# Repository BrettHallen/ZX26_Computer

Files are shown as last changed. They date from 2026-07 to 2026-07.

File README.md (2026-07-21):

# ZX26 Computer
I thought it might be interested to have a crack at designing a simple ZX81 clone that utilised the services of the vLA81.<br>

## [Issue 1](/Issue1)
This is my first attempt, just to see if it'll work.  I have left off the expansion connector for now.<br>

The design includes:
- Gateron low-profile keyswitches
- Dedicated cursor key cluster
- Atari-compatible joystick interface
- "FIRE" selectable between ZERO and SPACE keys
- 32KB of RAM (three schemes selectable via vLA81)
- 32KB of ROM (four switchable 8KB banks, i.e. original BASIC, modernised BASIC, ASZMIC assembler, ZX81 FORTH)
- 5V power in using a USB Type B connector (nice 'n' solid)
- Baseband video output selectable between NTSC (USA) and PAL (UK)

## vLA81
Utilising [VRetro's modern ULA replacement](https://www.vretrodesign.com/products/vla81-zx81-ula-replacement) to simplify parts & design.<br>

## Parts
Refer to the BOM for all parts.<br>

Some specific parts (i.e. footprints) I've utilised are:
- USB Type B: Same Sky UJ2-B-HR-G-TH
- RCA Jack: Kobiconn 156-0099-E
- 3.5mm Mono Jack: Same Sky SJ3-350820B
- DE9 Plug: Amphenol L717SDE09PA4CH4FC309 (or similar)

## Useful Information
- https://oldcomputer.info/8bit/zx81/ULA/ula.htm
- https://hackaday.io/project/192473-zx80zx81-remakes

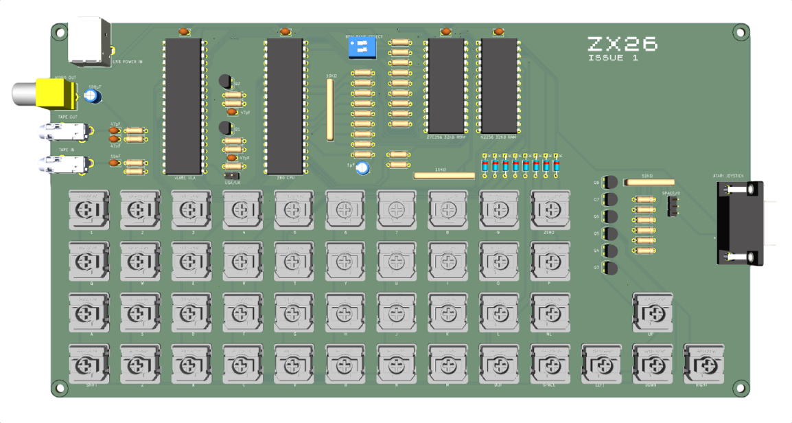
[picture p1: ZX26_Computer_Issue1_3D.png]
3D render of Issue 1


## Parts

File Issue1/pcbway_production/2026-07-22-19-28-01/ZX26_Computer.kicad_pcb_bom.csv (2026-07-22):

Designator | Quantity | Value | Footprint | Package | MPN | DNP | Mount_Type | Description | KiLib_Generator | Sim.Device | Sim.Pins | Height | Mouser Part Number | Mouser Price/Stock | Manufacturer_Name
C1, C10, C2 | 3 | 47pF | C_Disc_D3.8mm_W2.6mm_P2.50mm |  |  |  | tht | Unpolarized capacitor | capacitor/THT/other
C11 | 1 | 47nF | C_Disc_D3.8mm_W2.6mm_P2.50mm |  |  |  | tht | Unpolarized capacitor | capacitor/THT/other
C3 | 1 | 1µF | CP_Radial_D5.0mm_P2.50mm |  |  |  | tht | Polarized capacitor | capacitor/THT/other
C4, C5, C6, C7 | 4 | 100nF | C_Disc_D3.8mm_W2.6mm_P2.50mm |  |  |  | tht | Unpolarized capacitor | capacitor/THT/other
C8 | 1 | 100µF | CP_Radial_D5.0mm_P2.50mm |  |  |  | tht | Polarized capacitor | capacitor/THT/other
C9 | 1 | 10nF | C_Disc_D3.8mm_W2.6mm_P2.50mm |  |  |  | tht | Unpolarized capacitor | capacitor/THT/other
D1, D2, D3, D4, D5, D6, D7, D8 | 8 | 1N4148 | D_DO-35_SOD27_P7.62mm_Horizontal |  |  |  | tht | Diode | diode/THT | D | 1=K 2=A
J1 | 1 | USB POWER IN | UJ2BHRGTH |  | UJ2-B-HR-G-TH |  | tht | Type B, USB 2.0, 480 Mbps, 5 Vdc, 1.5 A, Right Angle, Through Hole Mounting Style, Through Hole Contact Pin Type, Board Lock, 0.6 in Plating Thickness, Black Insulator, Pick & Place, USB Receptacle |  |  |  | 11.1 | 179-UJ2-B-HR-G-TH | https://www.mouser.co.uk/ProductDetail/Same-Sky/UJ2-B-HR-G-TH?qs=HoCaDK9Nz5cuzuu5C%2FN7nw%3D%3D | Same Sky
J2 | 1 | ATARI JOYSTICK | DSUB-9_Pins_Horizontal_P2.77x2.84mm_EdgePinOffset7.70mm_Housed_MountingHolesOffset9.12mm |  |  |  | tht | 9-pin D-SUB connector, pins (male), Mounting Hole | connector/D_sub
J3 | 1 | FIRE MAPPING | PinHeader_1x03_P2.54mm_Vertical |  |  |  | tht | Generic connector, single row, 01x03, script generated (kicad-library-utils/schlib/autogen/connector/) | connector/pin_header_socket
J4 | 1 | VIDEO OUT | 1560099E |  |  |  | tht | coaxial connector (BNC, SMA, SMB, SMC, Cinch/RCA, LEMO, ...)
J5 | 1 | TAPE IN (EAR) | SJ3350820BTR |  |  |  | tht | Audio Jack, 2 Poles (Mono / TS)
J6 | 1 | TAPE OUT (MIC) | SJ3350820BTR |  |  |  | tht | Audio Jack, 2 Poles (Mono / TS)
Q1, Q2, Q3, Q4, Q5, Q6, Q7, Q8 | 8 | 2N3904 | TO-92_HandSolder |  |  |  | tht | 0.2A Ic, 40V Vce, Small Signal NPN Transistor, TO-92 |  | NPN | 1=E 2=B 3=C
R1, R15, R18, R19, R2, R20, R21, R22, R23, R24, R25, R3, R34, R4, R5, R6, R7, R8, R9 | 19 | 1KΩ | R_Axial_DIN0207_L6.3mm_D2.5mm_P7.62mm_Horizontal |  |  |  | tht | Resistor | resistor/THT
R10 | 1 | 2.2KΩ | R_Axial_DIN0207_L6.3mm_D2.5mm_P7.62mm_Horizontal |  |  |  | tht | Resistor | resistor/THT
R11 | 1 | 330Ω | R_Axial_DIN0207_L6.3mm_D2.5mm_P7.62mm_Horizontal |  |  |  | tht | Resistor | resistor/THT
R12, R13 | 2 | 680Ω | R_Axial_DIN0207_L6.3mm_D2.5mm_P7.62mm_Horizontal |  |  |  | tht | Resistor | resistor/THT
R14 | 1 | 10KΩ | R_Axial_DIN0207_L6.3mm_D2.5mm_P7.62mm_Horizontal |  |  |  | tht | Resistor | resistor/THT
R16 | 1 | 220KΩ | R_Axial_DIN0207_L6.3mm_D2.5mm_P7.62mm_Horizontal |  |  |  | tht | Resistor | resistor/THT
R17 | 1 | 220Ω | R_Axial_DIN0207_L6.3mm_D2.5mm_P7.62mm_Horizontal |  |  |  | tht | Resistor | resistor/THT
R26 | 1 | 30Ω | R_Axial_DIN0207_L6.3mm_D2.5mm_P7.62mm_Horizontal |  |  |  | tht | Resistor | resistor/THT
R27, R28, R29, R30, R31, R32, R43 | 7 | 4.7KΩ | R_Axial_DIN0207_L6.3mm_D2.5mm_P7.62mm_Horizontal |  |  |  | tht | Resistor | resistor/THT
R33 | 1 | 1MΩ | R_Axial_DIN0207_L6.3mm_D2.5mm_P7.62mm_Horizontal |  |  |  | tht | Resistor | resistor/THT
RN2, RN3 | 2 | 10KΩ | R_Array_SIP9 |  |  |  | tht | 8 resistor network, star topology, bussed resistors, small symbol | resistor/array_SIP_THT
RN4 | 1 | 10KΩ | R_Array_SIP7 |  |  |  | tht | 6 resistor network, star topology, bussed resistors, small symbol | resistor/array_SIP_THT
SW1 | 1 | 1 | SW_Gateron_LowProfile_THT |  |  |  | tht | Push button switch, normally open, two pins, 45° tilted
SW10 | 1 | E | SW_Gateron_LowProfile_THT |  |  |  | tht | Push button switch, normally open, two pins, 45° tilted
SW11 | 1 | D | SW_Gateron_LowProfile_THT |  |  |  | tht | Push button switch, normally open, two pins, 45° tilted
SW12 | 1 | X | SW_Gateron_LowProfile_THT |  |  |  | tht | Push button switch, normally open, two pins, 45° tilted
SW13 | 1 | 4 | SW_Gateron_LowProfile_THT |  |  |  | tht | Push button switch, normally open, two pins, 45° tilted
SW14 | 1 | R | SW_Gateron_LowProfile_THT |  |  |  | tht | Push button switch, normally open, two pins, 45° tilted
SW15 | 1 | F | SW_Gateron_LowProfile_THT |  |  |  | tht | Push button switch, normally open, two pins, 45° tilted
SW16 | 1 | C | SW_Gateron_LowProfile_THT |  |  |  | tht | Push button switch, normally open, two pins, 45° tilted
SW17 | 1 | 5 | SW_Gateron_LowProfile_THT |  |  |  | tht | Push button switch, normally open, two pins, 45° tilted
SW18 | 1 | T | SW_Gateron_LowProfile_THT |  |  |  | tht | Push button switch, normally open, two pins, 45° tilted
SW19 | 1 | G | SW_Gateron_LowProfile_THT |  |  |  | tht | Push button switch, normally open, two pins, 45° tilted
SW2 | 1 | Q | SW_Gateron_LowProfile_THT |  |  |  | tht | Push button switch, normally open, two pins, 45° tilted
SW20 | 1 | V | SW_Gateron_LowProfile_THT |  |  |  | tht | Push button switch, normally open, two pins, 45° tilted
SW21 | 1 | 6 | SW_Gateron_LowProfile_THT |  |  |  | tht | Push button switch, normally open, two pins, 45° tilted
SW22 | 1 | Y | SW_Gateron_LowProfile_THT |  |  |  | tht | Push button switch, normally open, two pins, 45° tilted
SW23 | 1 | H | SW_Gateron_LowProfile_THT |  |  |  | tht | Push button switch, normally open, two pins, 45° tilted
SW24 | 1 | B | SW_Gateron_LowProfile_THT |  |  |  | tht | Push button switch, normally open, two pins, 45° tilted
SW25 | 1 | 7 | SW_Gateron_LowProfile_THT |  |  |  | tht | Push button switch, normally open, two pins, 45° tilted
SW26 | 1 | U | SW_Gateron_LowProfile_THT |  |  |  | tht | Push button switch, normally open, two pins, 45° tilted
SW27 | 1 | J | SW_Gateron_LowProfile_THT |  |  |  | tht | Push button switch, normally open, two pins, 45° tilted
SW28 | 1 | N | SW_Gateron_LowProfile_THT |  |  |  | tht | Push button switch, normally open, two pins, 45° tilted
SW29 | 1 | 8 | SW_Gateron_LowProfile_THT |  |  |  | tht | Push button switch, normally open, two pins, 45° tilted
SW3 | 1 | A | SW_Gateron_LowProfile_THT |  |  |  | tht | Push button switch, normally open, two pins, 45° tilted
SW30 | 1 | I | SW_Gateron_LowProfile_THT |  |  |  | tht | Push button switch, normally open, two pins, 45° tilted
SW31 | 1 | K | SW_Gateron_LowProfile_THT |  |  |  | tht | Push button switch, normally open, two pins, 45° tilted
SW32 | 1 | M | SW_Gateron_LowProfile_THT |  |  |  | tht | Push button switch, normally open, two pins, 45° tilted
SW33 | 1 | 9 | SW_Gateron_LowProfile_THT |  |  |  | tht | Push button switch, normally open, two pins, 45° tilted
SW34 | 1 | O | SW_Gateron_LowProfile_THT |  |  |  | tht | Push button switch, normally open, two pins, 45° tilted
SW35 | 1 | L | SW_Gateron_LowProfile_THT |  |  |  | tht | Push button switch, normally open, two pins, 45° tilted
SW36 | 1 | DOT | SW_Gateron_LowProfile_THT |  |  |  | tht | Push button switch, normally open, two pins, 45° tilted
SW37 | 1 | ZERO | SW_Gateron_LowProfile_THT |  |  |  | tht | Push button switch, normally open, two pins, 45° tilted
SW38 | 1 | P | SW_Gateron_LowProfile_THT |  |  |  | tht | Push button switch, normally open, two pins, 45° tilted
SW39 | 1 | NL | SW_Gateron_LowProfile_THT |  |  |  | tht | Push button switch, normally open, two pins, 45° tilted
SW4 | 1 | SHIFT | SW_Gateron_LowProfile_THT |  |  |  | tht | Push button switch, normally open, two pins, 45° tilted
SW40 | 1 | SPACE | SW_Gateron_LowProfile_THT |  |  |  | tht | Push button switch, normally open, two pins, 45° tilted
SW41 | 1 | ROM BANK SELECT | SW_DIP_SPSTx02_Slide_9.78x7.26mm_W7.62mm_P2.54mm |  |  |  | tht | 2x DIP Switch, Single Pole Single Throw (SPST) switch, small symbol | button_switch/DIP
SW42 | 1 | USA/UK | PinHeader_1x02_P2.54mm_Vertical |  |  |  | tht | Single Pole Single Throw (SPST) switch | connector/pin_header_socket
SW43 | 1 | LEFT | SW_Gateron_LowProfile_THT |  |  |  | tht | Push button switch, normally open, two pins, 45° tilted
SW44 | 1 | DOWN | SW_Gateron_LowProfile_THT |  |  |  | tht | Push button switch, normally open, two pins, 45° tilted
SW45 | 1 | UP | SW_Gateron_LowProfile_THT |  |  |  | tht | Push button switch, normally open, two pins, 45° tilted
SW46 | 1 | RIGHT | SW_Gateron_LowProfile_THT |  |  |  | tht | Push button switch, normally open, two pins, 45° tilted
SW5 | 1 | 2 | SW_Gateron_LowProfile_THT |  |  |  | tht | Push button switch, normally open, two pins, 45° tilted
SW6 | 1 | W | SW_Gateron_LowProfile_THT |  |  |  | tht | Push button switch, normally open, two pins, 45° tilted
SW7 | 1 | S | SW_Gateron_LowProfile_THT |  |  |  | tht | Push button switch, normally open, two pins, 45° tilted
SW8 | 1 | Z | SW_Gateron_LowProfile_THT |  |  |  | tht | Push button switch, normally open, two pins, 45° tilted
SW9 | 1 | 3 | SW_Gateron_LowProfile_THT |  |  |  | tht | Push button switch, normally open, two pins, 45° tilted
U1 | 1 | vLA81 ULA | DIP-40_W15.24mm |  |  |  | tht |  | package/DIP/legacy
U2 | 1 | 62256 32KB RAM | DIP-28_W15.24mm |  |  |  | tht | 32,768-word × 8-bit High Speed CMOS Static RAM, 70ns, DIP-28 | package/DIP/legacy
U3 | 1 | Z80 CPU | DIP-40_W15.24mm |  |  |  | tht | 8-bit General Purpose Microprocessor, 8-bit data bus, 16-bit address bus, up to 6.17 / 8 / 10 / 20 MHz, CMOS version, DIP-40 (600 mil) | package/DIP/legacy
U4 | 1 | 27C256 32KB ROM | DIP-28_W15.24mm |  |  |  | tht | OTP EPROM 256 KiBit | package/DIP/legacy

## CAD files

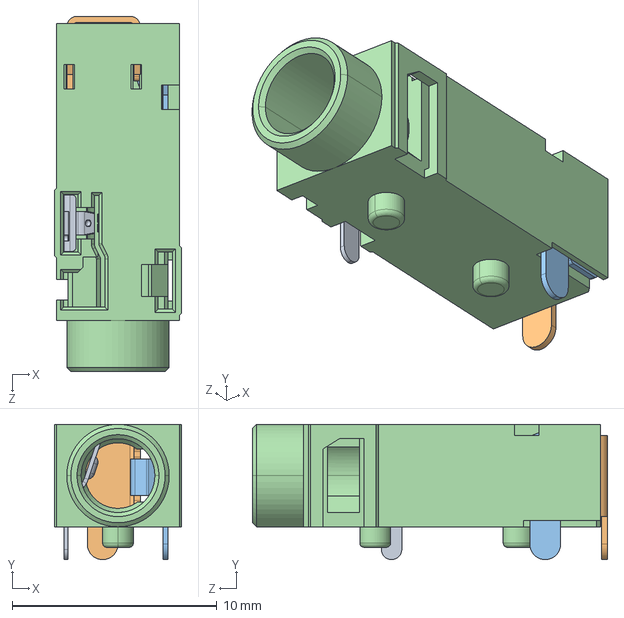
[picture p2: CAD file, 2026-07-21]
Datasheets/Audio_Jack/SJ3-350820B-TR.stp
6.20 x 6.60 x 17.3 mm

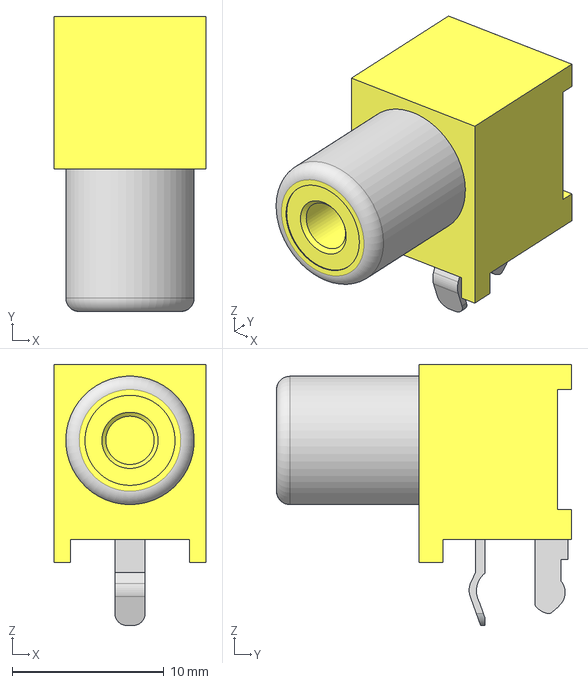
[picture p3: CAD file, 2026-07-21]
Datasheets/RCA_Jack/156-0099-E.stp
10.0 x 19.5 x 17.2 mm

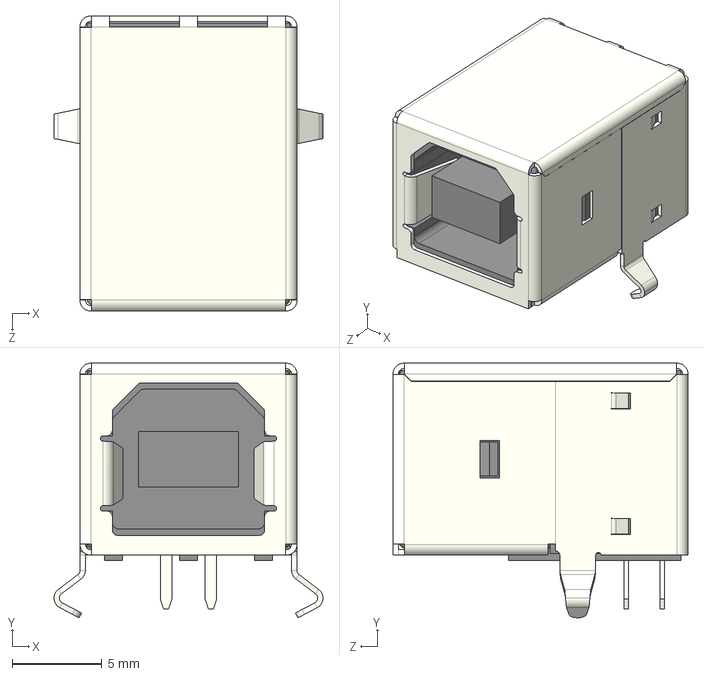
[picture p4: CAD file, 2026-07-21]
Datasheets/USB_Type_B/UJ2-B-HR-G-TH.stp
15.0 x 14.2 x 16.5 mm

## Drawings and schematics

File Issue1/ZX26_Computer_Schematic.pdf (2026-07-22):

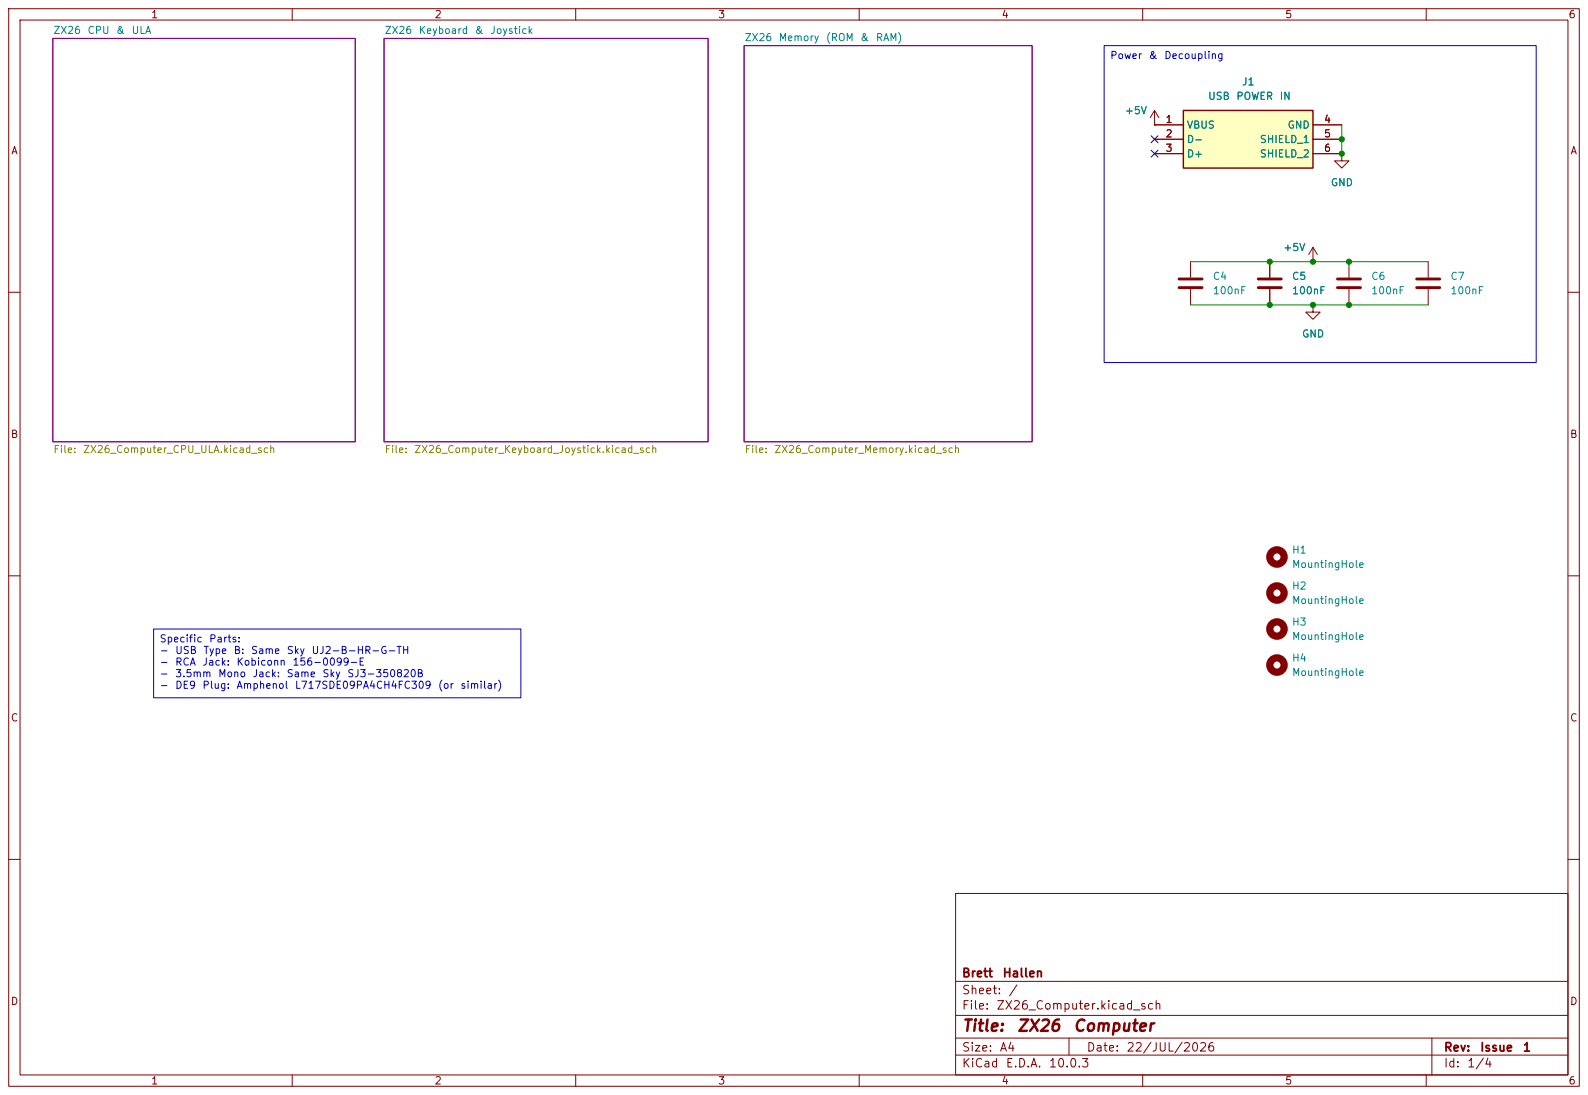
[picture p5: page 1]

Size: A4 | Rev: Issue 1
KiCad E.D.A. 10.0.3 | Id: 1/4

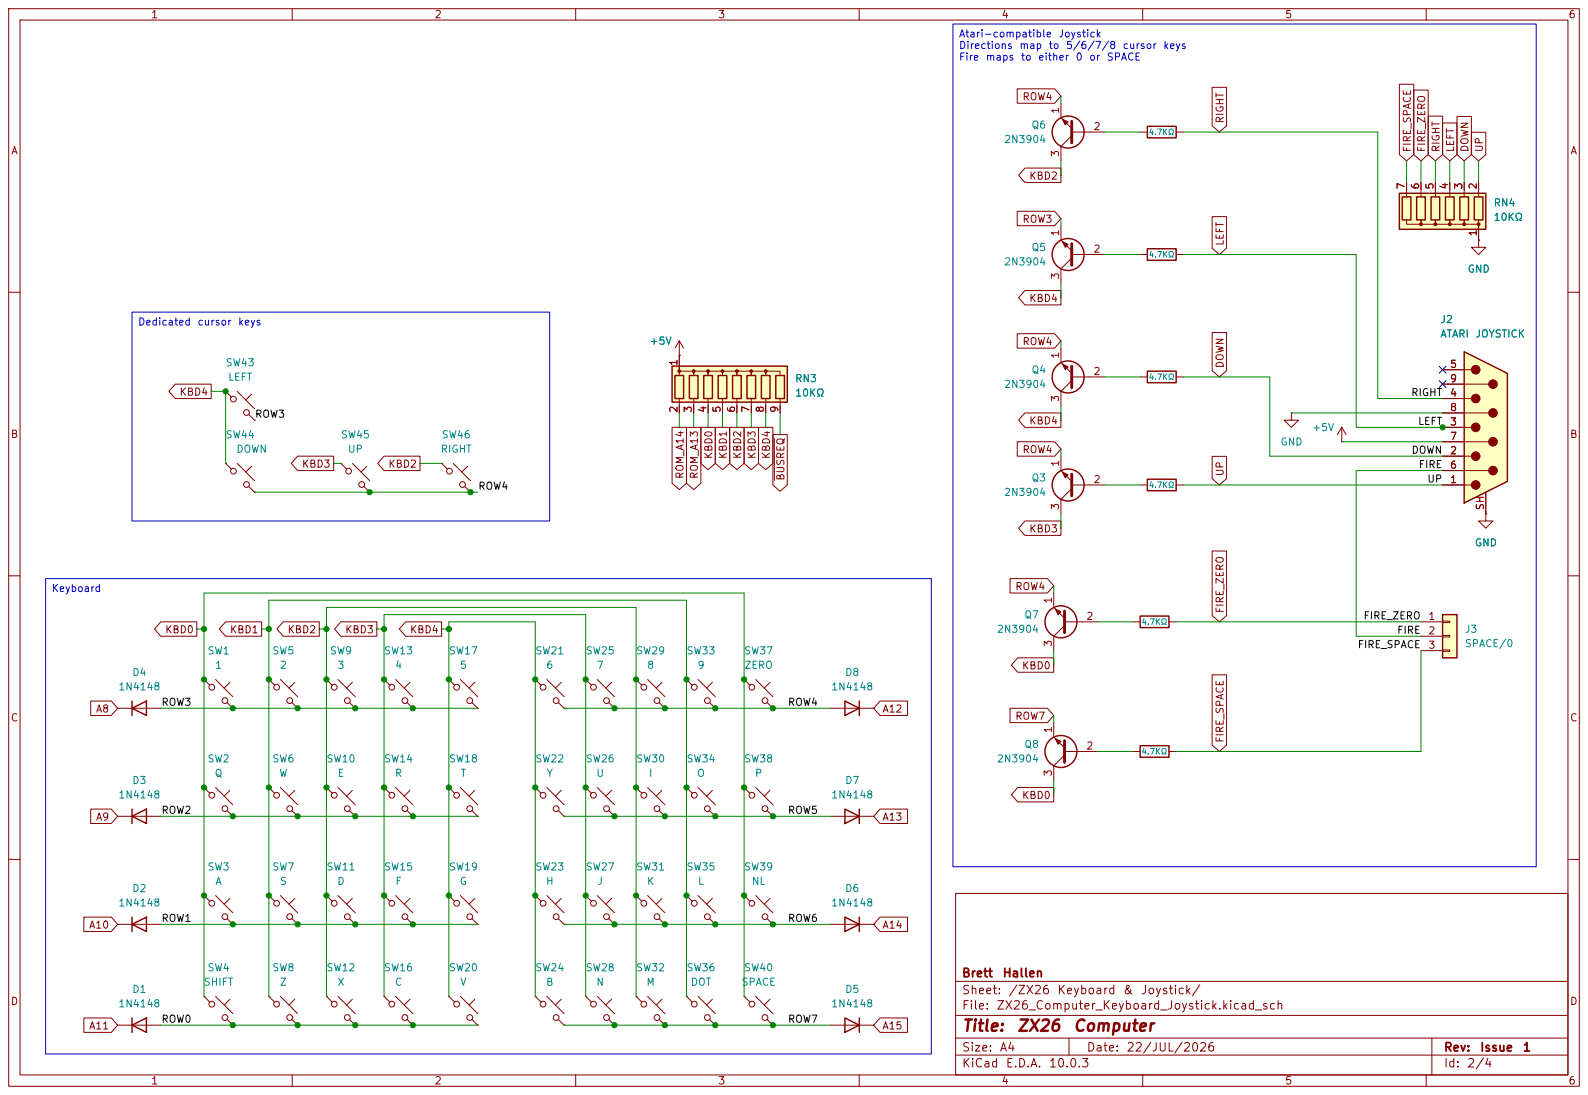
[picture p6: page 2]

ATARI JOYSTICK
FIRE RIGHT LEFT DOWN

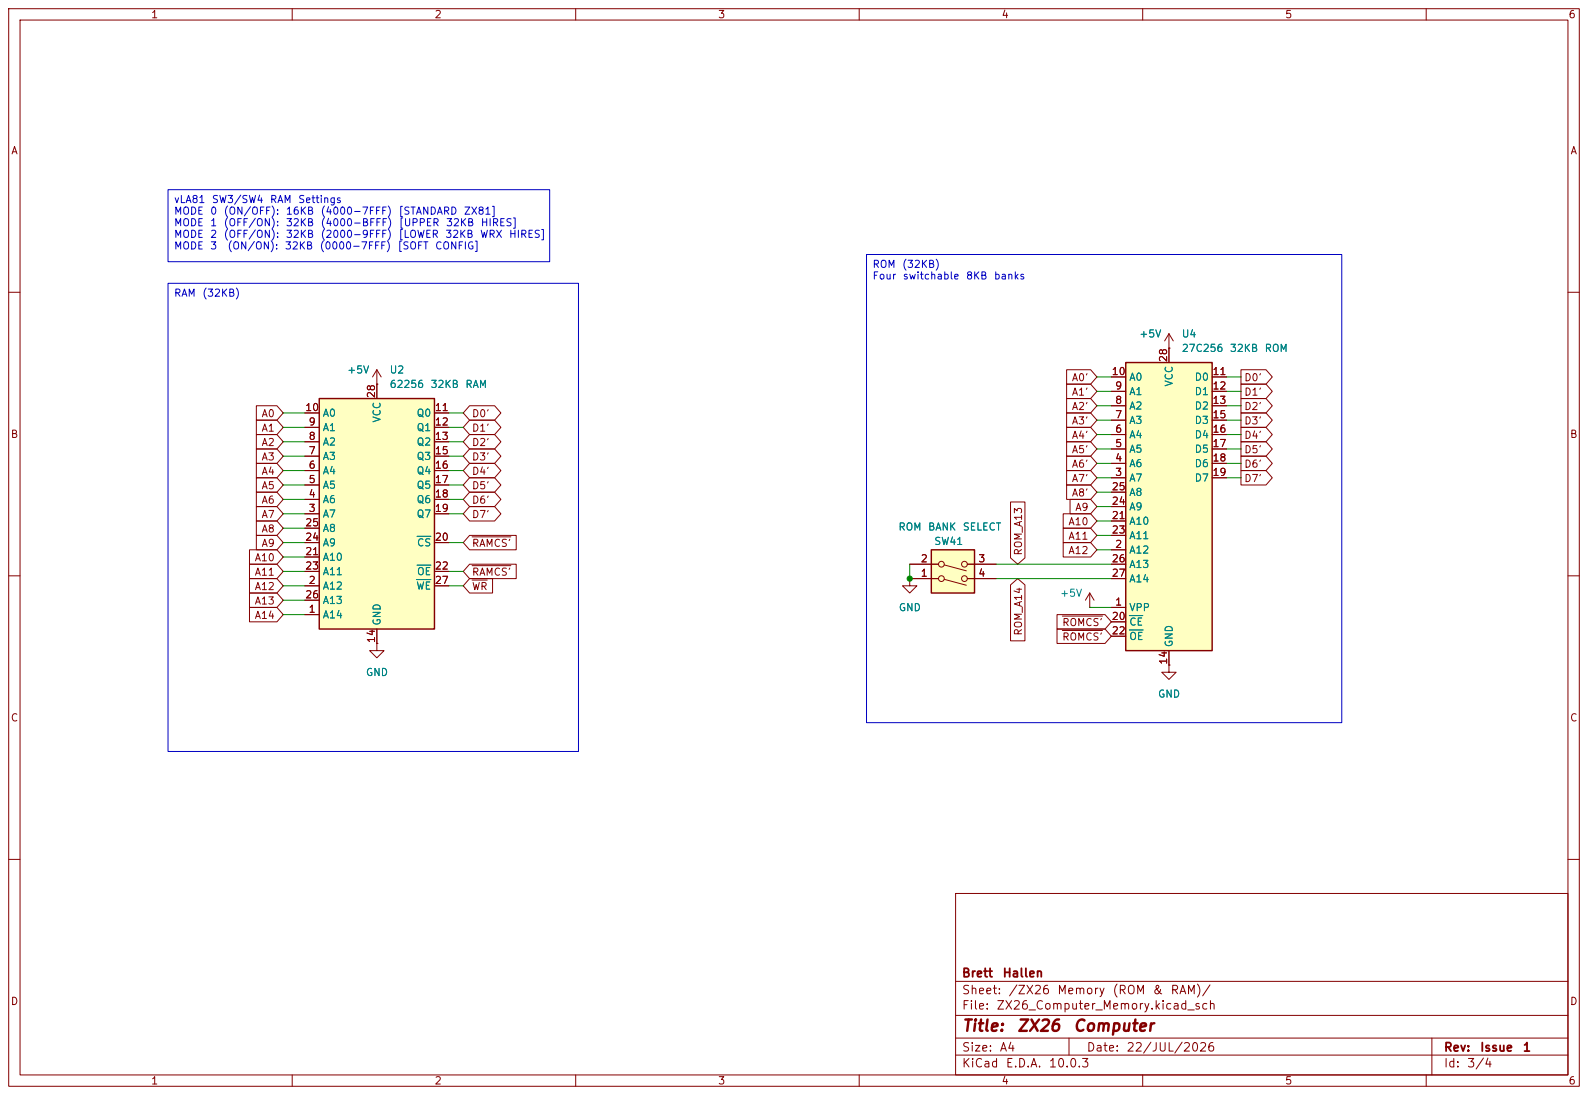
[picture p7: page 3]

Brett Hallen
Sheet: /ZX26 Memory (ROM & RAM)/
File: ZX26_Computer_Memory.kicad_sch
Title: ZX26 Computer

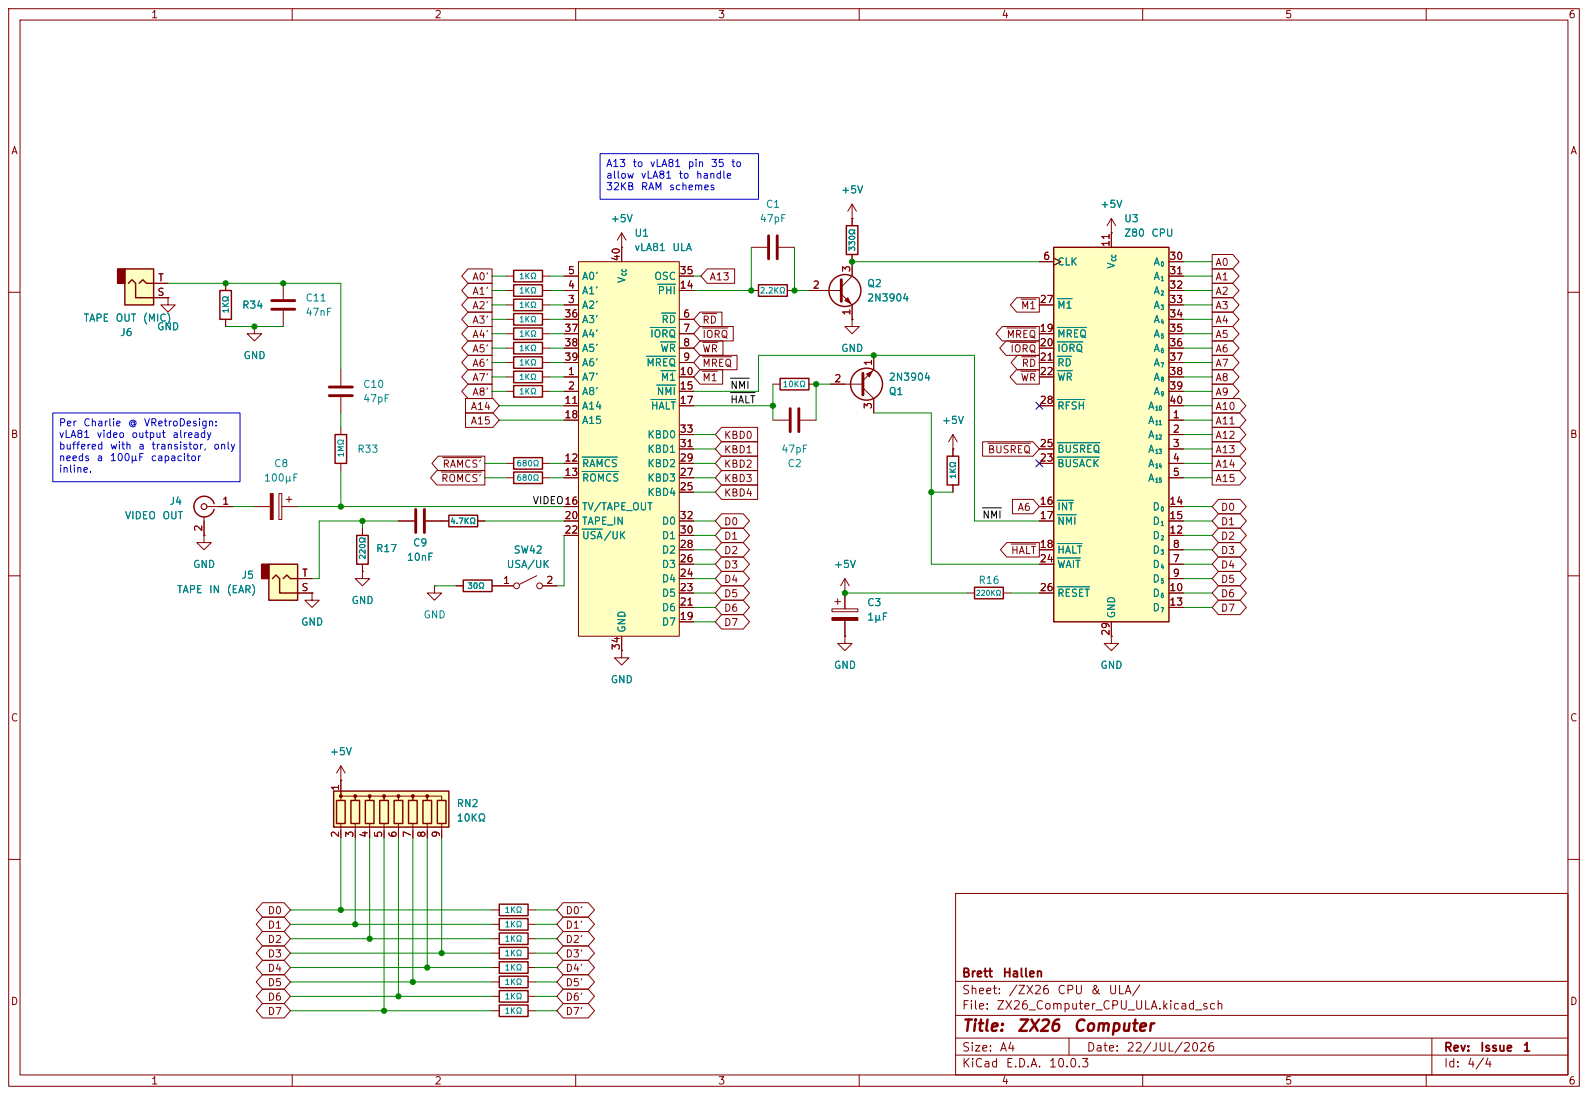
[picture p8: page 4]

NMI HALT NMI A13 to vLA81 pin 35 to

allow vLA81 to handle 32KB RAM schemes Per Charlie @ VRetroDesign: vLA81 video output already buffered with a transistor, only needs a 100µF capacitor

V CC 11 D2 12 D7 13 D0 14 D1 15 INT 16 NMI 17 HALT 18 MREQ 19

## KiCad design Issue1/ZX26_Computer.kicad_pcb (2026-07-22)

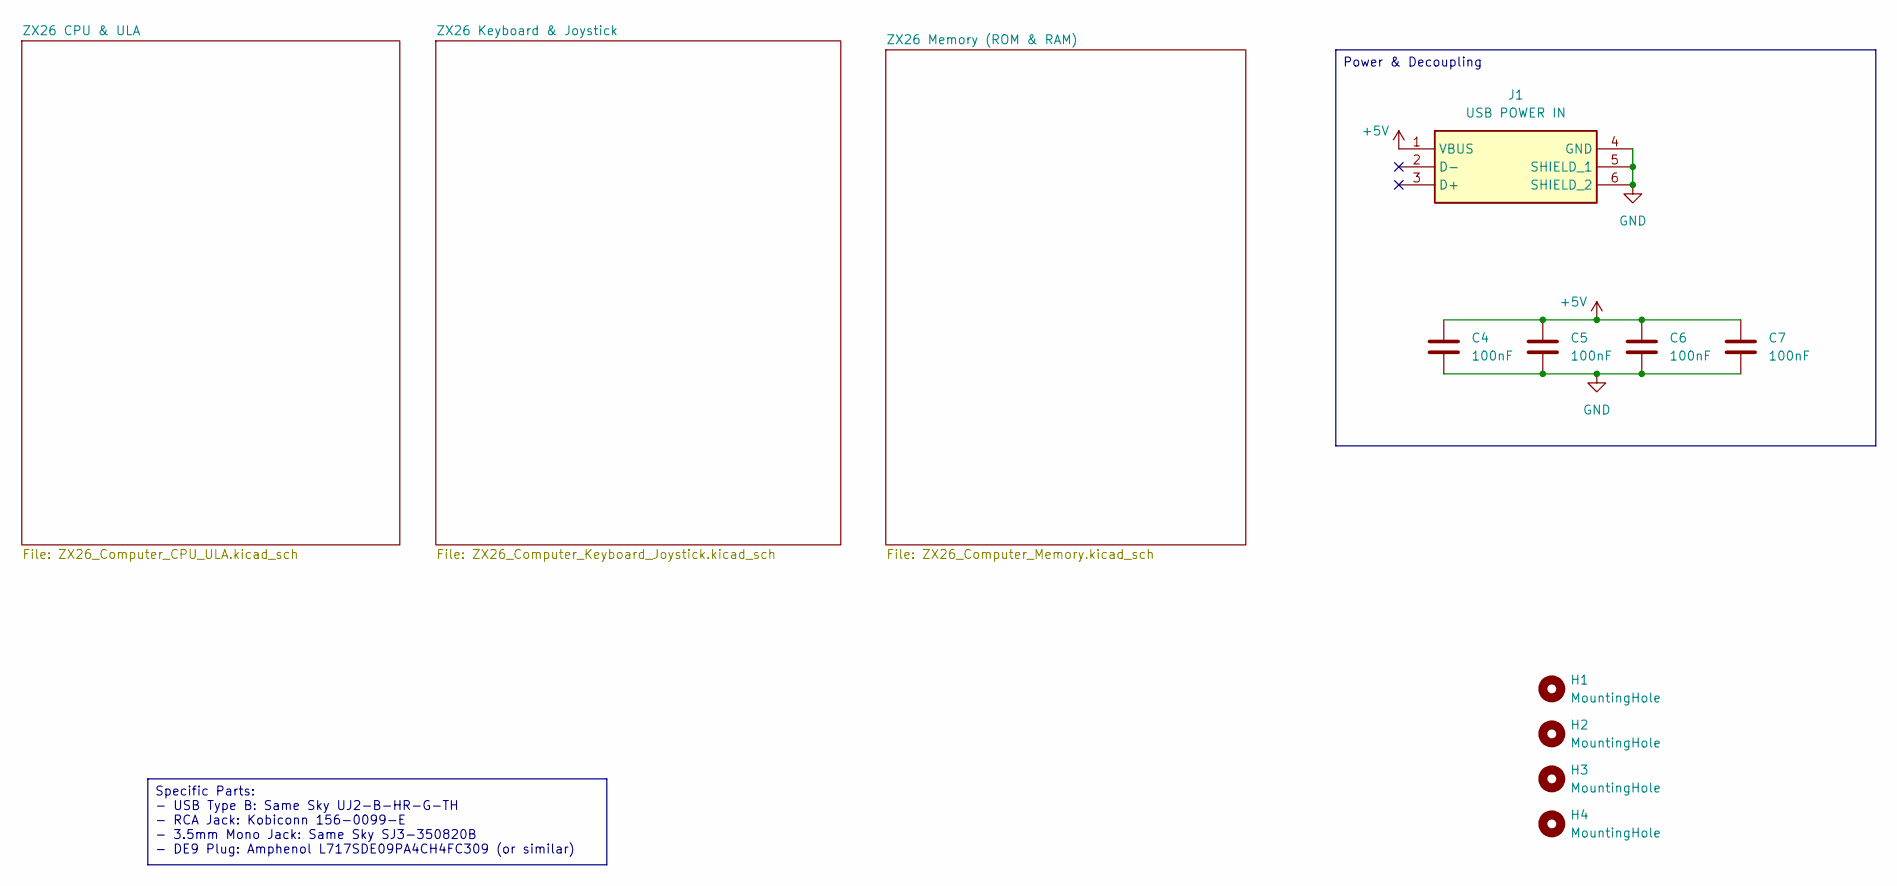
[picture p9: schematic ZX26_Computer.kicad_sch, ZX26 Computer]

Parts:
C4, C5, C6, C7: 100nF; C_Disc_D3.8mm_W2.6mm_P2.50mm
H1, H2, H3, H4: MountingHole; MountingHole_3.2mm_M3
J1: USB POWER IN; UJ2BHRGTH; Mouser Part Number 179-UJ2-B-HR-G-TH

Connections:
+5V: C4.1, C5.1, C6.1, C7.1, J1.1 (VBUS); also elsewhere on the board
GND: C4.2, C5.2, C6.2, C7.2, J1.4 (GND), J1.5 (SHIELD_1), J1.6 (SHIELD_2); also elsewhere on the board

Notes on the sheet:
Specific Parts: - USB Type B: Same Sky UJ2-B-HR-G-TH - RCA Jack: Kobiconn 156-0099-E - 3.5mm Mono Jack: Same Sky SJ3-350820B - DE9 Plug: Amphenol L717SDE09PA4CH4FC309 (or similar)
Power & Decoupling

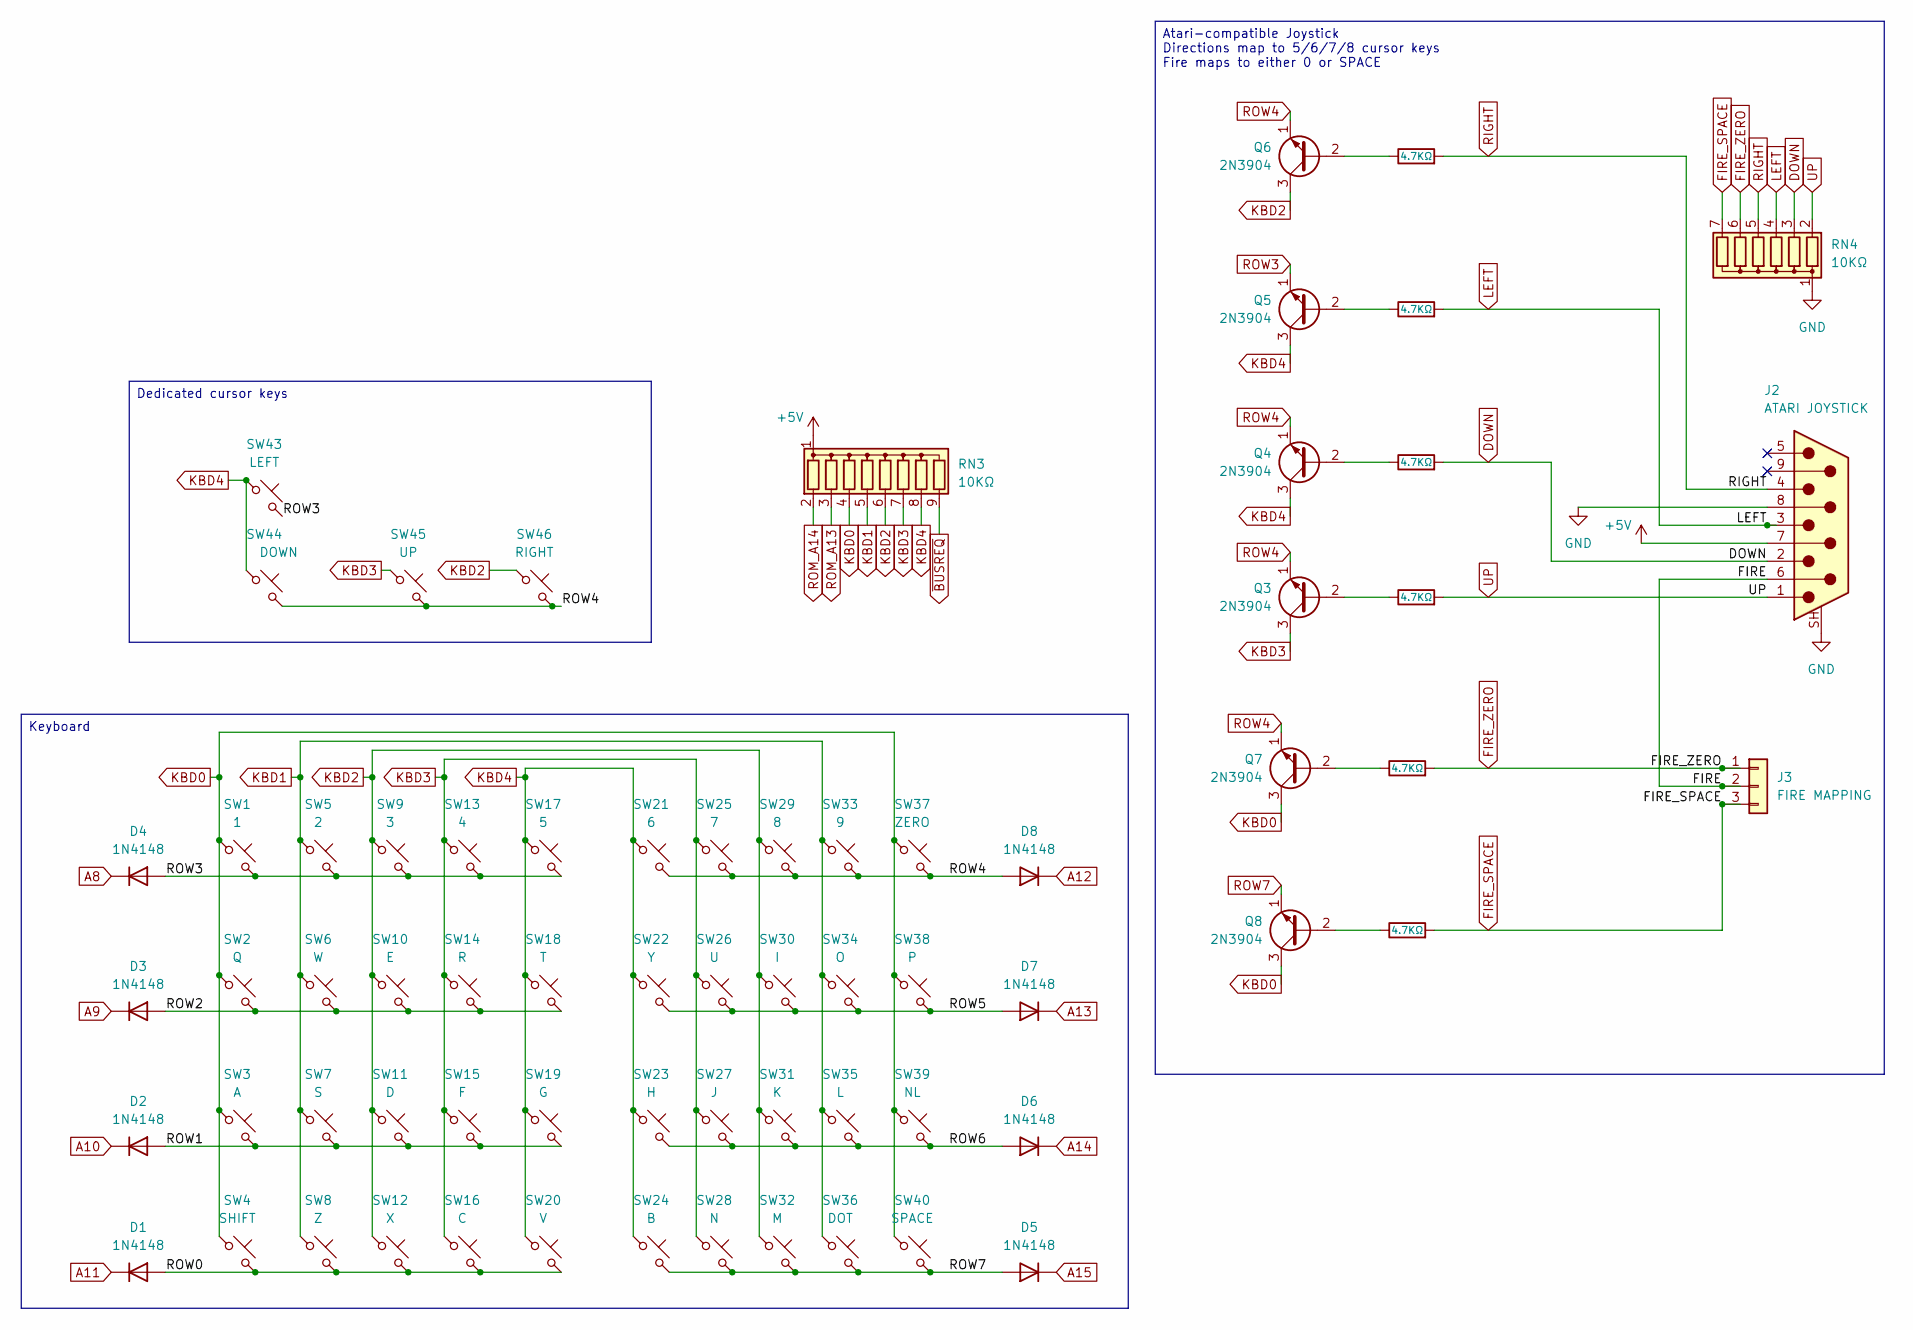
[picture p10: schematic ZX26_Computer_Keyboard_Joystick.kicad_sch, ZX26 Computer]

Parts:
D1, D2, D3, D4, D5, D6, D7, D8: 1N4148; D_DO-35_SOD27_P7.62mm_Horizontal
J2: ATARI JOYSTICK; DSUB-9_Pins_Horizontal_P2.77x2.84mm_EdgePinOffset7.70mm_Hou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
J3: FIRE MAPPING; PinHeader_1x03_P2.54mm_Vertical
Q3, Q4, Q5, Q6, Q7, Q8: 2N3904; TO-92_HandSolder
R27, R28, R29, R30, R31, R32: 4.7KΩ; R_Axial_DIN0207_L6.3mm_D2.5mm_P7.62mm_Horizontal
RN3: 10KΩ; R_Array_SIP9
RN4: 10KΩ; R_Array_SIP7
SW1: 1; SW_Gateron_LowProfile_THT
SW2: Q; SW_Gateron_LowProfile_THT
SW3: A; SW_Gateron_LowProfile_THT
SW4: SHIFT; SW_Gateron_LowProfile_THT
SW5: 2; SW_Gateron_LowProfile_THT
SW6: W; SW_Gateron_LowProfile_THT
SW7: S; SW_Gateron_LowProfile_THT
SW8: Z; SW_Gateron_LowProfile_THT
SW9: 3; SW_Gateron_LowProfile_THT
SW10: E; SW_Gateron_LowProfile_THT
SW11: D; SW_Gateron_LowProfile_THT
SW12: X; SW_Gateron_LowProfile_THT
SW13: 4; SW_Gateron_LowProfile_THT
SW14: R; SW_Gateron_LowProfile_THT
SW15: F; SW_Gateron_LowProfile_THT
SW16: C; SW_Gateron_LowProfile_THT
SW17: 5; SW_Gateron_LowProfile_THT
SW18: T; SW_Gateron_LowProfile_THT
SW19: G; SW_Gateron_LowProfile_THT
SW20: V; SW_Gateron_LowProfile_THT
SW21: 6; SW_Gateron_LowProfile_THT
SW22: Y; SW_Gateron_LowProfile_THT
SW23: H; SW_Gateron_LowProfile_THT
SW24: B; SW_Gateron_LowProfile_THT
SW25: 7; SW_Gateron_LowProfile_THT
SW26: U; SW_Gateron_LowProfile_THT
SW27: J; SW_Gateron_LowProfile_THT
SW28: N; SW_Gateron_LowProfile_THT
SW29: 8; SW_Gateron_LowProfile_THT
SW30: I; SW_Gateron_LowProfile_THT
SW31: K; SW_Gateron_LowProfile_THT
SW32: M; SW_Gateron_LowProfile_THT
SW33: 9; SW_Gateron_LowProfile_THT
SW34: O; SW_Gateron_LowProfile_THT
SW35: L; SW_Gateron_LowProfile_THT
SW36: DOT; SW_Gateron_LowProfile_THT
SW37: ZERO; SW_Gateron_LowProfile_THT
SW38: P; SW_Gateron_LowProfile_THT
SW39: NL; SW_Gateron_LowProfile_THT
SW40: SPACE; SW_Gateron_LowProfile_THT
SW43: LEFT; SW_Gateron_LowProfile_THT
SW44: DOWN; SW_Gateron_LowProfile_THT
SW45: UP; SW_Gateron_LowProfile_THT
SW46: RIGHT; SW_Gateron_LowProfile_THT

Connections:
+5V: J2.7, RN3.1 (common); also elsewhere on the board
/ZX26 Keyboard & Joystick/FIRE: J2.6, J3.2
/ZX26 Keyboard & Joystick/ROW0: D1.2 (A), SW4.2, SW8.2, SW12.2, SW16.2, SW20.2
/ZX26 Keyboard & Joystick/ROW1: D2.2 (A), SW3.2, SW7.2, SW11.2, SW15.2, SW19.2
/ZX26 Keyboard & Joystick/ROW2: D3.2 (A), SW2.2, SW6.2, SW10.2, SW14.2, SW18.2
/ZX26 Keyboard & Joystick/ROW5: D7.2 (A), SW22.2, SW26.2, SW30.2, SW34.2, SW38.2
/ZX26 Keyboard & Joystick/ROW6: D6.2 (A), SW23.2, SW27.2, SW31.2, SW35.2, SW39.2
A8: D4.1 (K); also elsewhere on the board
A9: D3.1 (K); also elsewhere on the board
A10: D2.1 (K); also elsewhere on the board
A11: D1.1 (K); also elsewhere on the board
A12: D8.1 (K); also elsewhere on the board
A13: D7.1 (K); also elsewhere on the board
A14: D6.1 (K); also elsewhere on the board
A15: D5.1 (K); also elsewhere on the board
DOWN: J2.2, R28.2, RN4.3 (R2)
FIRE_SPACE: J3.3, R32.2, RN4.7 (R6)
FIRE_ZERO: J3.1, R31.2, RN4.6 (R5)
GND: J2.8, J2.SH (PAD), RN4.1 (common); also elsewhere on the board
KBD0: Q7.3 (C), Q8.3 (C), RN3.4 (R3), SW1.1, SW2.1, SW3.1, SW4.1, SW37.1, SW38.1, SW39.1, SW40.1; also elsewhere on the board
KBD1: RN3.5 (R4), SW5.1, SW6.1, SW7.1, SW8.1, SW33.1, SW34.1, SW35.1, SW36.1; also elsewhere on the board
KBD2: Q6.3 (C), RN3.6 (R5), SW9.1, SW10.1, SW11.1, SW12.1, SW29.1, SW30.1, SW31.1, SW32.1, SW46.1; also elsewhere on the board
KBD3: Q3.3 (C), RN3.7 (R6), SW13.1, SW14.1, SW15.1, SW16.1, SW25.1, SW26.1, SW27.1, SW28.1, SW45.1; also elsewhere on the board
KBD4: Q4.3 (C), Q5.3 (C), RN3.8 (R7), SW17.1, SW18.1, SW19.1, SW20.1, SW21.1, SW22.1, SW23.1, SW24.1, SW43.1, SW44.1; also elsewhere on the board
LEFT: J2.3, R29.2, RN4.4 (R3)
unnamed: Q3.2 (B), R27.1
unnamed: Q4.2 (B), R28.1
unnamed: Q5.2 (B), R29.1
unnamed: Q6.2 (B), R30.1
unnamed: Q7.2 (B), R31.1
unnamed: Q8.2 (B), R32.1
RIGHT: J2.4, R30.2, RN4.5 (R4)
ROM_A13: RN3.3 (R2); also elsewhere on the board
ROM_A14: RN3.2 (R1); also elsewhere on the board
ROW3: D4.2 (A), Q5.1 (E), SW1.2, SW5.2, SW9.2, SW13.2, SW17.2, SW43.2
ROW4: D8.2 (A), Q3.1 (E), Q4.1 (E), Q6.1 (E), Q7.1 (E), SW21.2, SW25.2, SW29.2, SW33.2, SW37.2, SW44.2, SW45.2, SW46.2
ROW7: D5.2 (A), Q8.1 (E), SW24.2, SW28.2, SW32.2, SW36.2, SW40.2
UP: J2.1, R27.2, RN4.2 (R1)
~BUSREQ: RN3.9 (R8); also elsewhere on the board

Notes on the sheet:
Dedicated cursor keys
Keyboard
Atari-compatible Joystick Directions map to 5/6/7/8 cursor keys Fire maps to either 0 or SPACE

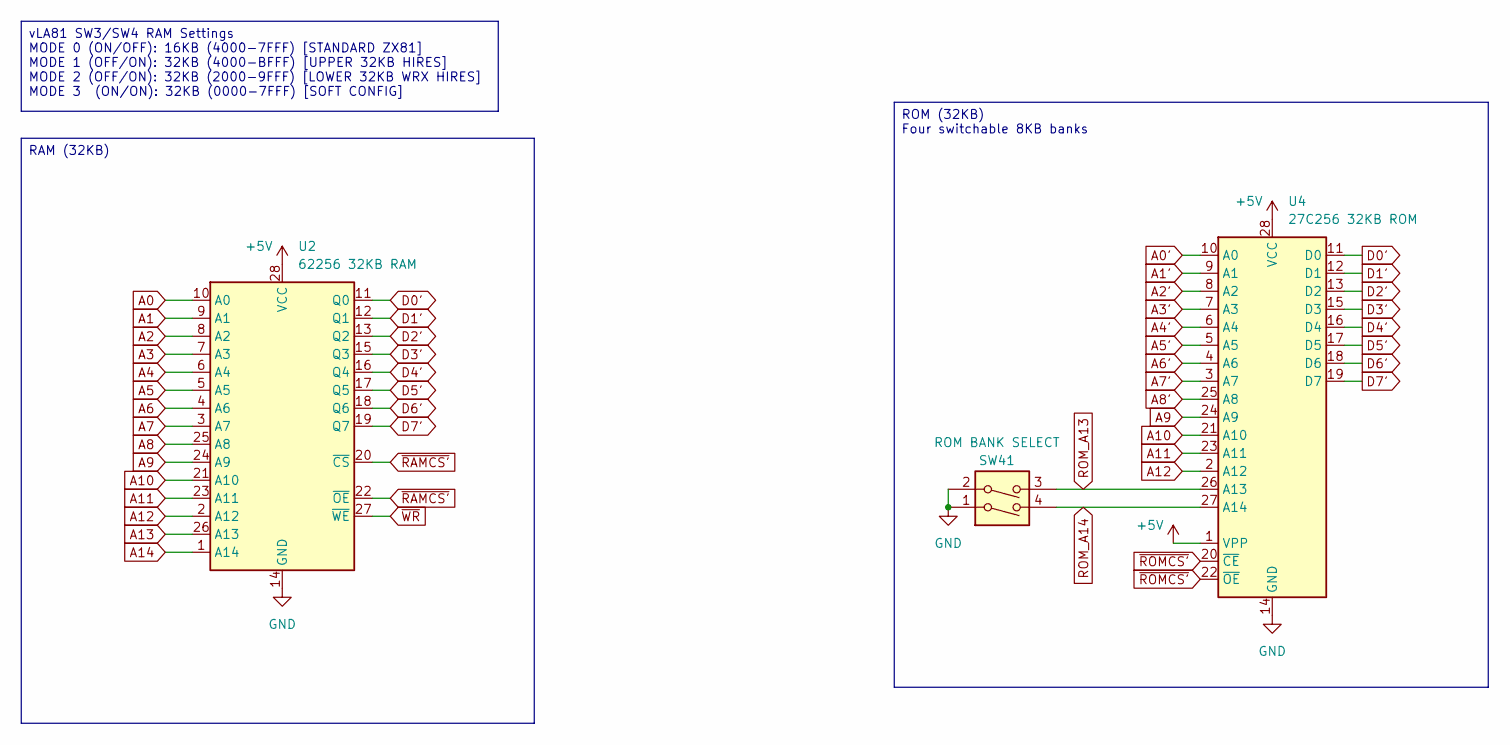
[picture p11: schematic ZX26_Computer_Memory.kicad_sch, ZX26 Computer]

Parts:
SW41: ROM BANK SELECT; SW_DIP_SPSTx02_Slide_9.78x7.26mm_W7.62mm_P2.54mm
U2: 62256 32KB RAM; DIP-28_W15.24mm
U4: 27C256 32KB ROM; DIP-28_W15.24mm

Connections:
+5V: U2.28 (VCC), U4.1 (VPP), U4.28 (VCC); also elsewhere on the board
A0: U2.10 (A0); also elsewhere on the board
A0': U4.10 (A0); also elsewhere on the board
A1: U2.9 (A1); also elsewhere on the board
A1': U4.9 (A1); also elsewhere on the board
A2: U2.8 (A2); also elsewhere on the board
A2': U4.8 (A2); also elsewhere on the board
A3: U2.7 (A3); also elsewhere on the board
A3': U4.7 (A3); also elsewhere on the board
A4: U2.6 (A4); also elsewhere on the board
A4': U4.6 (A4); also elsewhere on the board
A5: U2.5 (A5); also elsewhere on the board
A5': U4.5 (A5); also elsewhere on the board
A6: U2.4 (A6); also elsewhere on the board
A6': U4.4 (A6); also elsewhere on the board
A7: U2.3 (A7); also elsewhere on the board
A7': U4.3 (A7); also elsewhere on the board
A8: U2.25 (A8); also elsewhere on the board
A8': U4.25 (A8); also elsewhere on the board
A9: U2.24 (A9), U4.24 (A9); also elsewhere on the board
A10: U2.21 (A10), U4.21 (A10); also elsewhere on the board
A11: U2.23 (A11), U4.23 (A11); also elsewhere on the board
A12: U2.2 (A12), U4.2 (A12); also elsewhere on the board
A13: U2.26 (A13); also elsewhere on the board
A14: U2.1 (A14); also elsewhere on the board
D0': U2.11 (Q0), U4.11 (D0); also elsewhere on the board
D1': U2.12 (Q1), U4.12 (D1); also elsewhere on the board
D2': U2.13 (Q2), U4.13 (D2); also elsewhere on the board
D3': U2.15 (Q3), U4.15 (D3); also elsewhere on the board
D4': U2.16 (Q4), U4.16 (D4); also elsewhere on the board
D5': U2.17 (Q5), U4.17 (D5); also elsewhere on the board
D6': U2.18 (Q6), U4.18 (D6); also elsewhere on the board
D7': U2.19 (Q7), U4.19 (D7); also elsewhere on the board
GND: SW41.1, SW41.2, U2.14 (GND), U4.14 (GND); also elsewhere on the board
ROM_A13: SW41.3, U4.26 (A13); also elsewhere on the board
ROM_A14: SW41.4, U4.27 (A14); also elsewhere on the board
~RAMCS': U2.20 (~CS), U2.22 (~OE); also elsewhere on the board
~ROMCS': U4.20 (~CE), U4.22 (~OE); also elsewhere on the board
~WR: U2.27 (~WE); also elsewhere on the board

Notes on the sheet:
RAM (32KB)
ROM (32KB) Four switchable 8KB banks
vLA81 SW3/SW4 RAM Settings MODE 0 (ON/OFF): 16KB (4000-7FFF) [STANDARD ZX81] MODE 1 (OFF/ON): 32KB (4000-BFFF) [UPPER 32KB HIRES] MODE 2 (OFF/ON): 32KB (2000-9FFF) [LOWER 32KB WRX HIRES] MODE 3 (ON/ON): 32KB (0000-7FFF) [SOFT CONFIG]

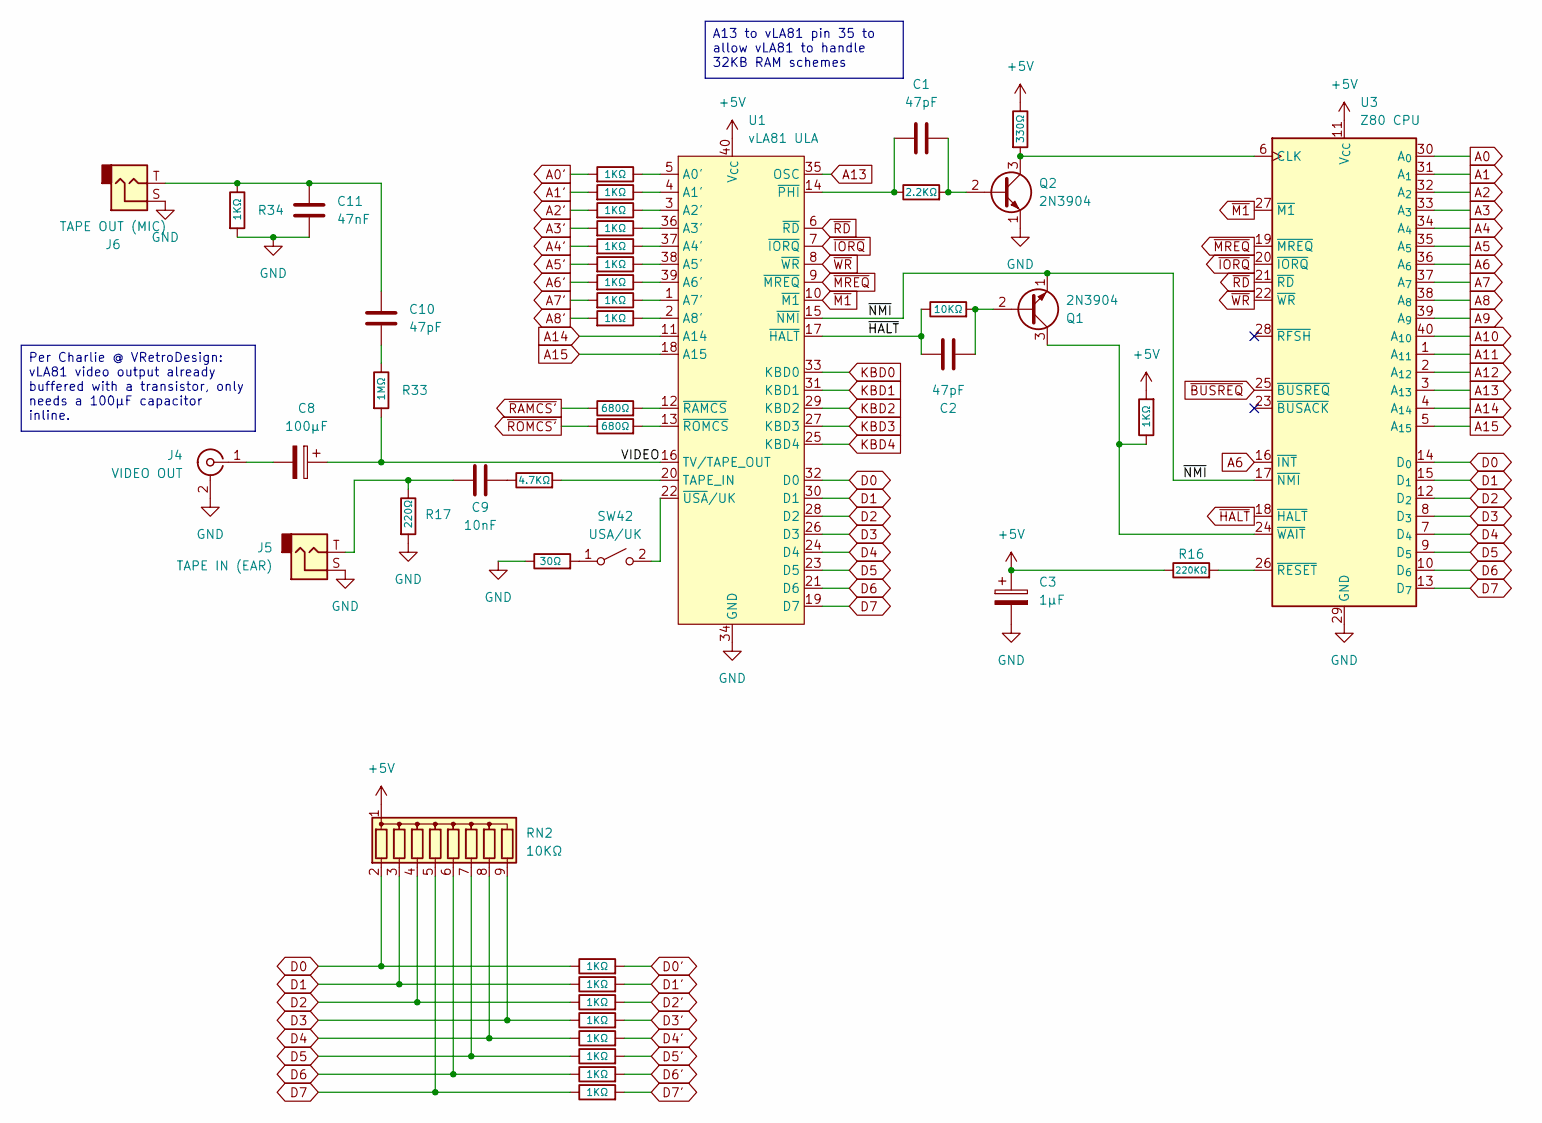
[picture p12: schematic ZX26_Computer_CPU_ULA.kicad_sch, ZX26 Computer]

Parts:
C1, C2, C10: 47pF; C_Disc_D3.8mm_W2.6mm_P2.50mm
C3: 1µF; CP_Radial_D5.0mm_P2.50mm
C8: 100µF; CP_Radial_D5.0mm_P2.50mm
C9: 10nF; C_Disc_D3.8mm_W2.6mm_P2.50mm
C11: 47nF; C_Disc_D3.8mm_W2.6mm_P2.50mm
J4: VIDEO OUT; 1560099E
J5: TAPE IN (EAR); SJ3350820BTR
J6: TAPE OUT (MIC); SJ3350820BTR
Q1, Q2: 2N3904; TO-92_HandSolder
R1, R2, R3, R4, R5, R6, R7, R8, R9, R15, R18, R19, R20, R21, R22, R23, R24, R25, R34: 1KΩ; R_Axial_DIN0207_L6.3mm_D2.5mm_P7.62mm_Horizontal
R10: 2.2KΩ; R_Axial_DIN0207_L6.3mm_D2.5mm_P7.62mm_Horizontal
R11: 330Ω; R_Axial_DIN0207_L6.3mm_D2.5mm_P7.62mm_Horizontal
R12, R13: 680Ω; R_Axial_DIN0207_L6.3mm_D2.5mm_P7.62mm_Horizontal
R14: 10KΩ; R_Axial_DIN0207_L6.3mm_D2.5mm_P7.62mm_Horizontal
R16: 220KΩ; R_Axial_DIN0207_L6.3mm_D2.5mm_P7.62mm_Horizontal
R17: 220Ω; R_Axial_DIN0207_L6.3mm_D2.5mm_P7.62mm_Horizontal
R26: 30Ω; R_Axial_DIN0207_L6.3mm_D2.5mm_P7.62mm_Horizontal
R33: 1MΩ; R_Axial_DIN0207_L6.3mm_D2.5mm_P7.62mm_Horizontal
R43: 4.7KΩ; R_Axial_DIN0207_L6.3mm_D2.5mm_P7.62mm_Horizontal
RN2: 10KΩ; R_Array_SIP9
SW42: USA/UK; PinHeader_1x02_P2.54mm_Vertical
U1: vLA81 ULA; DIP-40_W15.24mm
U3: Z80 CPU; DIP-40_W15.24mm

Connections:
+5V: C3.1, R11.1, R15.2, R16.1, RN2.1 (common), U1.40 (V_{CC}), U3.11 (V_{CC}); also elsewhere on the board
/ZX26 CPU & ULA/VIDEO: C8.1, R33.2, U1.16 (TV/TAPE_OUT)
/ZX26 CPU & ULA/~NMI: Q1.1 (E), U1.15 (~NMI), U3.17 (~NMI)
A0: U3.30 (A_{0}); also elsewhere on the board
A0': R1.2; also elsewhere on the board
A1: U3.31 (A_{1}); also elsewhere on the board
A1': R2.2; also elsewhere on the board
A2: U3.32 (A_{2}); also elsewhere on the board
A2': R3.2; also elsewhere on the board
A3: U3.33 (A_{3}); also elsewhere on the board
A3': R4.2; also elsewhere on the board
A4: U3.34 (A_{4}); also elsewhere on the board
A4': R5.2; also elsewhere on the board
A5: U3.35 (A_{5}); also elsewhere on the board
A5': R6.2; also elsewhere on the board
A6: U3.16 (~INT), U3.36 (A_{6}); also elsewhere on the board
A6': R7.2; also elsewhere on the board
A7: U3.37 (A_{7}); also elsewhere on the board
A7': R8.2; also elsewhere on the board
A8: U3.38 (A_{8}); also elsewhere on the board
A8': R9.2; also elsewhere on the board
A9: U3.39 (A_{9}); also elsewhere on the board
A10: U3.40 (A_{10}); also elsewhere on the board
A11: U3.1 (A_{11}); also elsewhere on the board
A12: U3.2 (A_{12}); also elsewhere on the board
A13: U1.35 (OSC), U3.3 (A_{13}); also elsewhere on the board
A14: U1.11 (A14), U3.4 (A_{14}); also elsewhere on the board
A15: U1.18 (A15), U3.5 (A_{15}); also elsewhere on the board
D0: R18.1, RN2.2 (R1), U1.32 (D0), U3.14 (D_{0})
D0': R18.2; also elsewhere on the board
D1: R19.1, RN2.3 (R2), U1.30 (D1), U3.15 (D_{1})
D1': R19.2; also elsewhere on the board
D2: R20.1, RN2.4 (R3), U1.28 (D2), U3.12 (D_{2})
D2': R20.2; also elsewhere on the board
D3: R21.1, RN2.9 (R8), U1.26 (D3), U3.8 (D_{3})
D3': R21.2; also elsewhere on the board
D4: R22.1, RN2.8 (R7), U1.24 (D4), U3.7 (D_{4})
D4': R22.2; also elsewhere on the board
D5: R23.1, RN2.7 (R6), U1.23 (D5), U3.9 (D_{5})
D5': R23.2; also elsewhere on the board
D6: R24.1, RN2.6 (R5), U1.21 (D6), U3.10 (D_{6})
D6': R24.2; also elsewhere on the board
D7: R25.1, RN2.5 (R4), U1.19 (D7), U3.13 (D_{7})
D7': R25.2; also elsewhere on the board
GND: C3.2, C11.2, J4.2 (Ext), J5.S, J6.S, Q2.1 (E), R17.2, R26.1, R34.2, U1.34 (GND), U3.29 (GND); also elsewhere on the board
KBD0: U1.33 (KBD0); also elsewhere on the board
KBD1: U1.31 (KBD1); also elsewhere on the board
KBD2: U1.29 (KBD2); also elsewhere on the board
KBD3: U1.27 (KBD3); also elsewhere on the board
KBD4: U1.25 (KBD4); also elsewhere on the board
unnamed: C9.1, J5.T, R17.1
unnamed: C9.2, R43.1
unnamed: C10.1, C11.1, J6.T, R34.1
unnamed: C10.2, R33.1
unnamed: C8.2, J4.1 (In)
unnamed: C2.2, Q1.2 (B), R14.2
unnamed: Q1.3 (C), R15.1, U3.24 (~WAIT)
unnamed: C1.2, Q2.2 (B), R10.2
unnamed: Q2.3 (C), R11.2, U3.6 (CLK)
unnamed: R26.2, SW42.1 (A)
unnamed: SW42.2 (B), U1.22 (~USA/UK)
unnamed: R1.1, U1.5 (A0')
unnamed: R2.1, U1.4 (A1')
unnamed: R3.1, U1.3 (A2')
unnamed: R4.1, U1.36 (A3')
unnamed: R5.1, U1.37 (A4')
unnamed: R6.1, U1.38 (A5')
unnamed: R7.1, U1.39 (A6')
unnamed: R8.1, U1.1 (A7')
unnamed: R9.1, U1.2 (A8')
unnamed: R43.2, U1.20 (TAPE_IN)
unnamed: C1.1, R10.1, U1.14 (~PHI)
unnamed: R13.2, U1.12 (~RAMCS)
unnamed: R12.2, U1.13 (~ROMCS)
unnamed: R16.2, U3.26 (~RESET)
~BUSREQ: U3.25 (~BUSREQ); also elsewhere on the board
~HALT: C2.1, R14.1, U1.17 (~HALT), U3.18 (~HALT)
~IORQ: U1.7 (~IORQ), U3.20 (~IORQ)
~M1: U1.10 (~M1), U3.27 (~M1)
~MREQ: U1.9 (~MREQ), U3.19 (~MREQ)
~RAMCS': R13.1; also elsewhere on the board
~RD: U1.6 (~RD), U3.21 (~RD)
~ROMCS': R12.1; also elsewhere on the board
~WR: U1.8 (~WR), U3.22 (~WR); also elsewhere on the board

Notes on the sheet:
A13 to vLA81 pin 35 to allow vLA81 to handle 32KB RAM schemes
Per Charlie @ VRetroDesign: vLA81 video output already buffered with a transistor, only needs a 100µF capacitor inline.

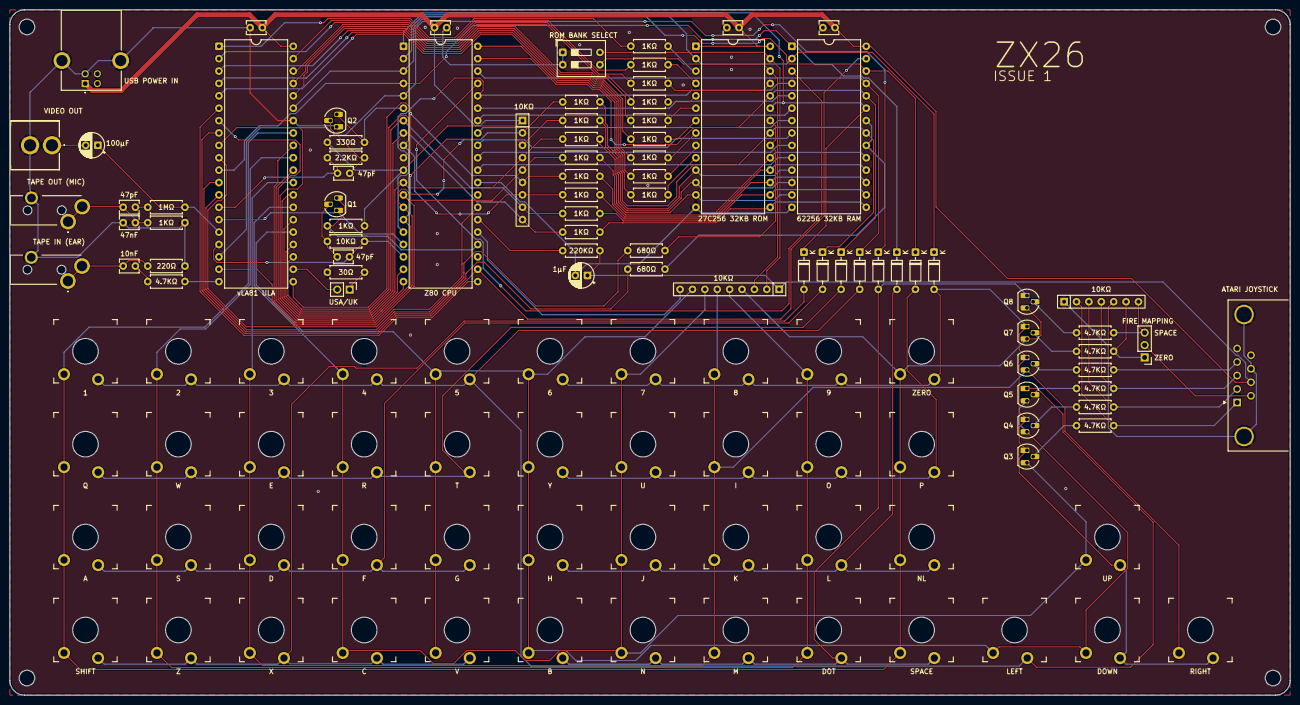
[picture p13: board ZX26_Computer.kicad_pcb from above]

Board: 2 copper layers, 262.5 x 140.5 mm, 125 parts (0 on the bottom side), 107 nets.

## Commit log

2026-07-21 Added DE9 part info
    [ZX26_Computer.kicad_sch]
2026-07-22 Minor PCB updates
    [ZX26_Computer.kicad_pcb, ZX26_Computer.kicad_pcb_bom.csv, ZX26_Computer.kicad_pcb_positions.csv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]
2026-07-22 Additional PCB text
    [ZX26_Computer.kicad_pcb, ZX26_Computer.kicad_pcb_bom.csv, ZX26_Computer.kicad_pcb_positions.csv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]
